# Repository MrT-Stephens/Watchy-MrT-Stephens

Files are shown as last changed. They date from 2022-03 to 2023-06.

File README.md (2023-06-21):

<h1 align="center">
  <br>
  MrT Stephens's Watchy GitHub Repo
  <br>
</h1>

<h4 align="center">This is my version of the Watchy E-Paper smartwatch by <a href="https://watchy.sqfmi.com" target="_blank">sqfmi</a>!</h4>

<p align="center">
  <a href="#watchy-esp32-s3">Watchy Esp32-S3</a> •
  <a href="#watchy-esp32-s3-specifications">Watchy Esp32-S3 specifications</a> •
   <a href="#watchy-esp32-s3-3d-models">Watchy Esp32-S3 3D-Models</a>
</p>

## Watchy Esp32-S3
***Current Version = V1.2***
> **Note**
> The version 1.2 has not been tested yet, as version 1.1 was having issues with the I2C bus.

## Watchy Esp32-S3 specifications
* MCU, ESP32-S3R8, Dual Core, 8MB Psram.
* Flash, 128Mbit, 16MB, W25Q128JVPIQ.
* Sensors.
   - BME688, Environmental Gas sensor.
   - BMP390, Pressure sensor.
   - BMA400, Accelerometer.
   - BMM150, Magnometer.
   - SHT41A, Temprature sensor.
   - DS3231MZ, Real Time clock.
* E-Paper Display, GDEH0154D67.
* Type C Port, USB4110-GF-A_REVB.
* PCB Antenna, swra117d.
* Tactical Buttons, K2-1114SA-A4SW-06.
* Vibration Motor.

## Watchy Esp32-S3 3D-Models
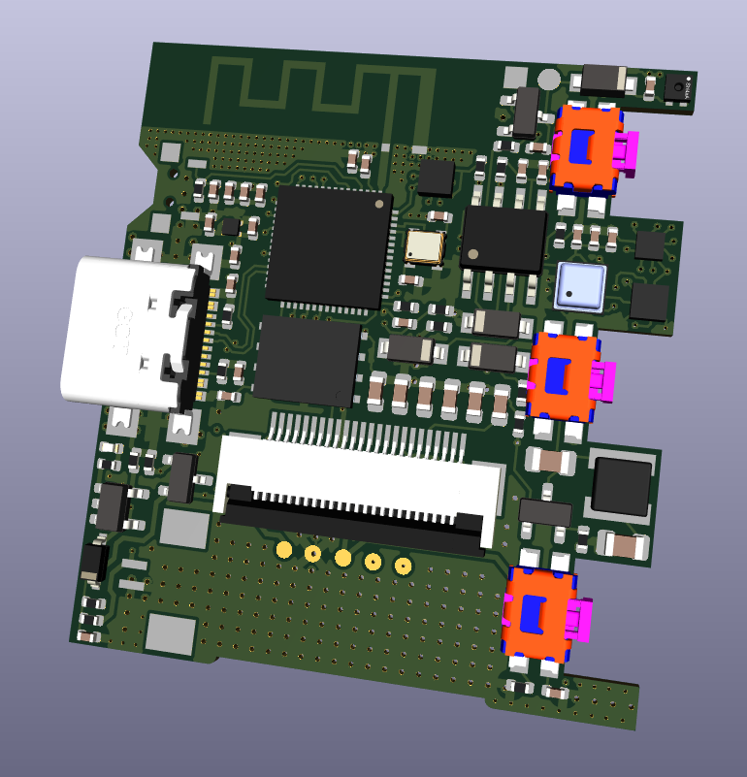
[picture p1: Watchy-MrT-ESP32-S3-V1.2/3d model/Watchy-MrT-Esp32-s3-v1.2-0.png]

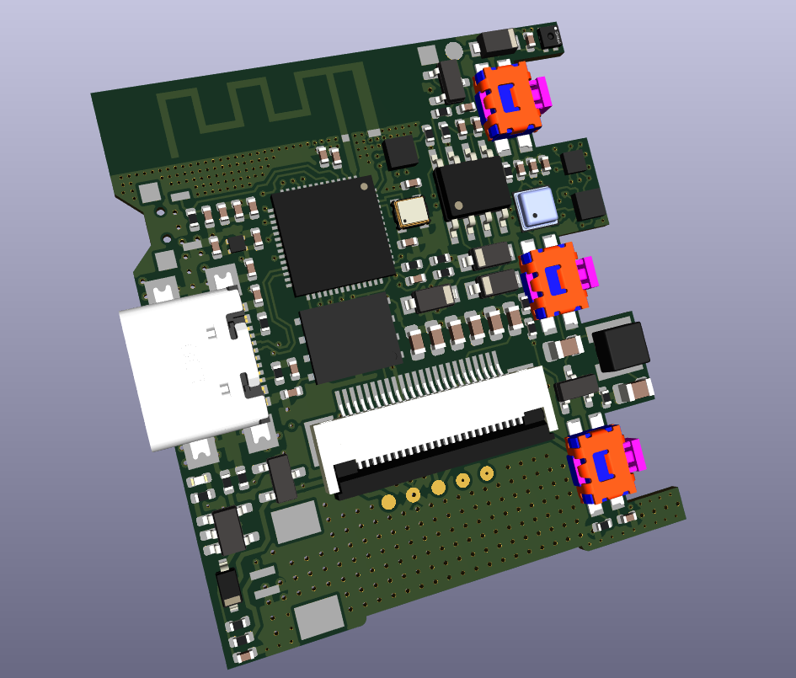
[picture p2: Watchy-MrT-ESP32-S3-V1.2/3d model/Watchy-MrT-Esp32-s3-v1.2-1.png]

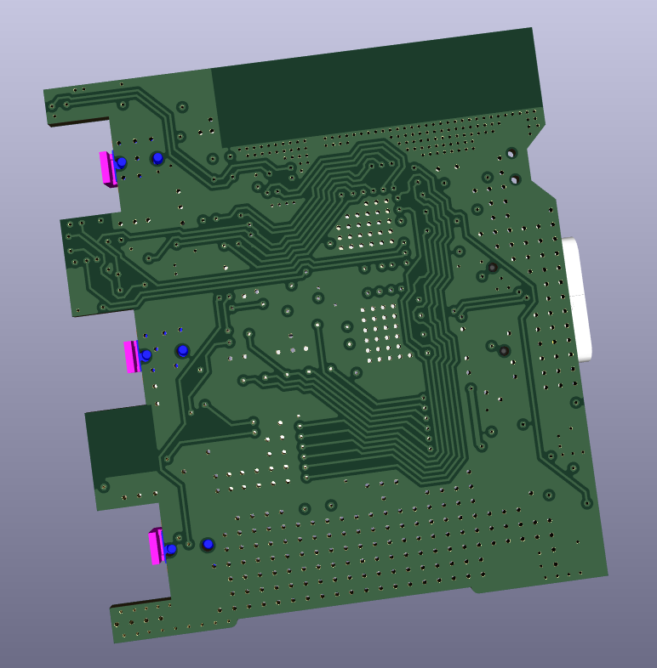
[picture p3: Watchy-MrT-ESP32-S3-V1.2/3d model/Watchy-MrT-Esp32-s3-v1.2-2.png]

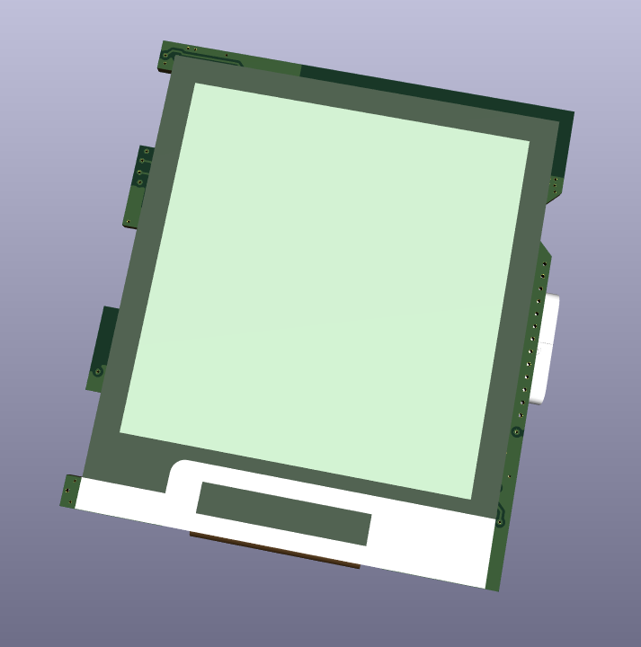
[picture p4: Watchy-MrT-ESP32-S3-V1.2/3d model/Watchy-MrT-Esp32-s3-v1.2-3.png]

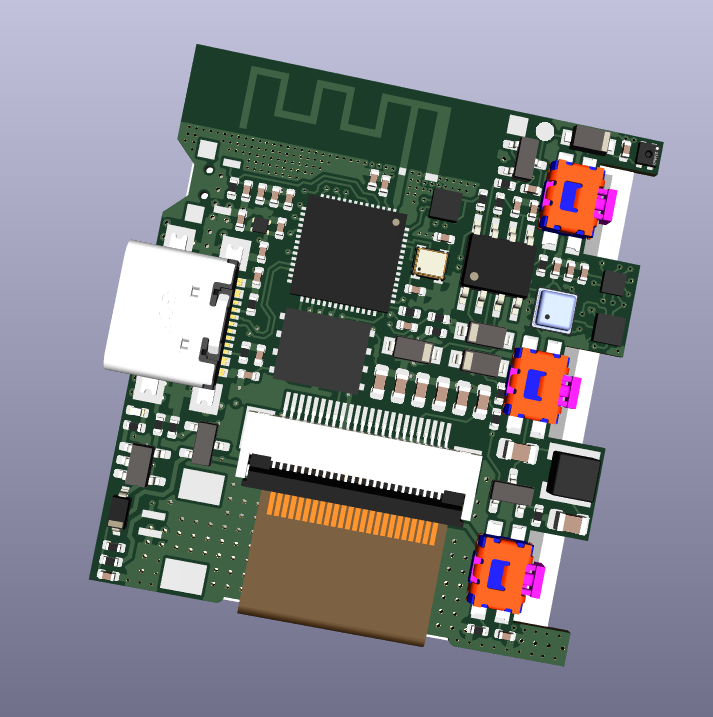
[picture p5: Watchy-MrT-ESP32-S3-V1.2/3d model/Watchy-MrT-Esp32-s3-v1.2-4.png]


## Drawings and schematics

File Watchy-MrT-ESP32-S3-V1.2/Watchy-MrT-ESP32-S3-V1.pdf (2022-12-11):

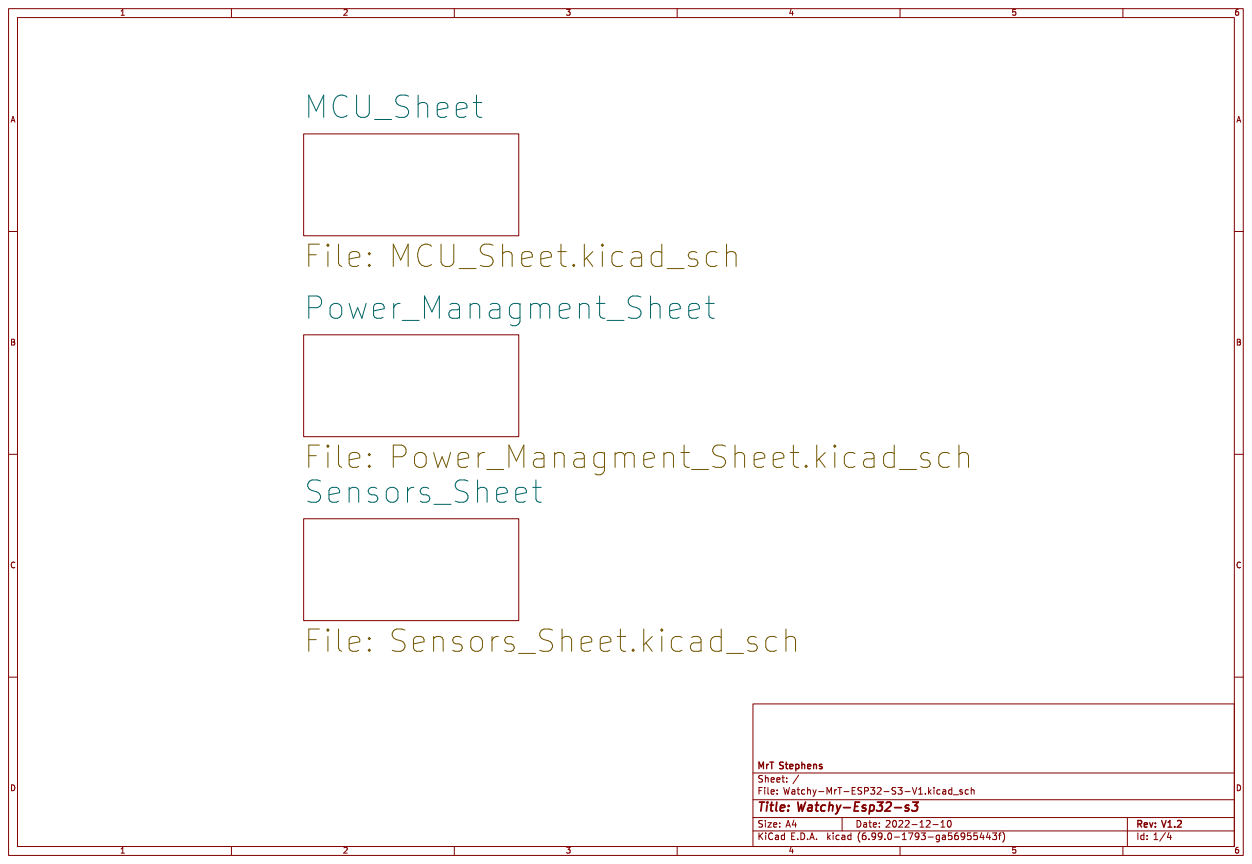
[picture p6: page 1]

File: Watchy-MrT-ESP32-S3-V1.kicad_sch Sheet: / MrT Stephens

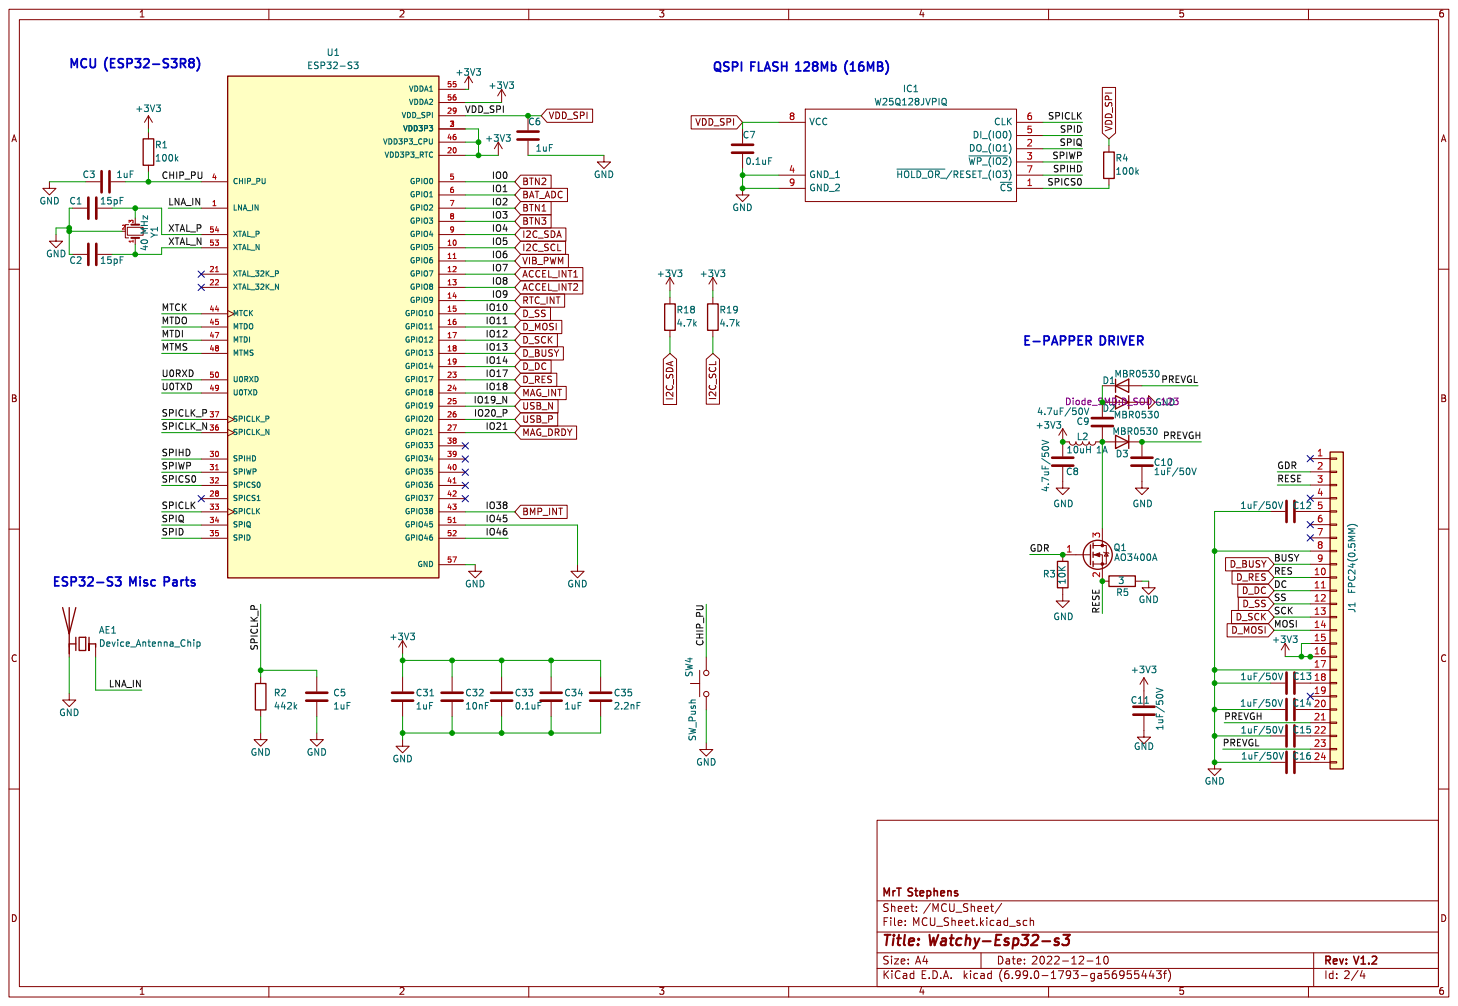
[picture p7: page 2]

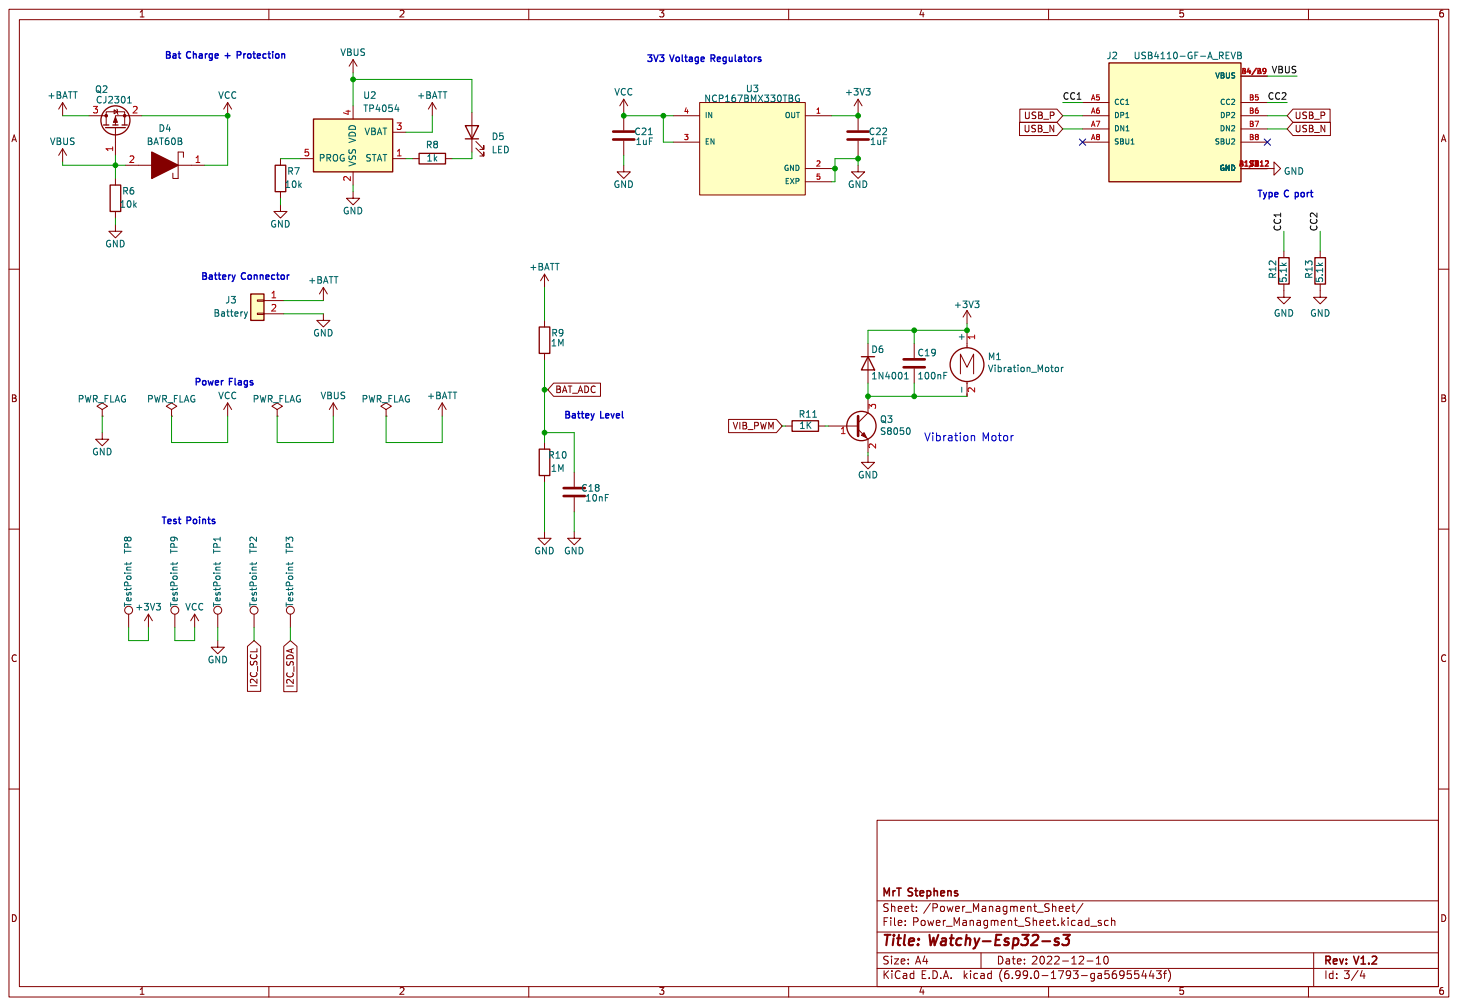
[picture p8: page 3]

Type C port Vibration Motor Bat Charge + Protection

Test Points Power Flags
PWR_FLAG

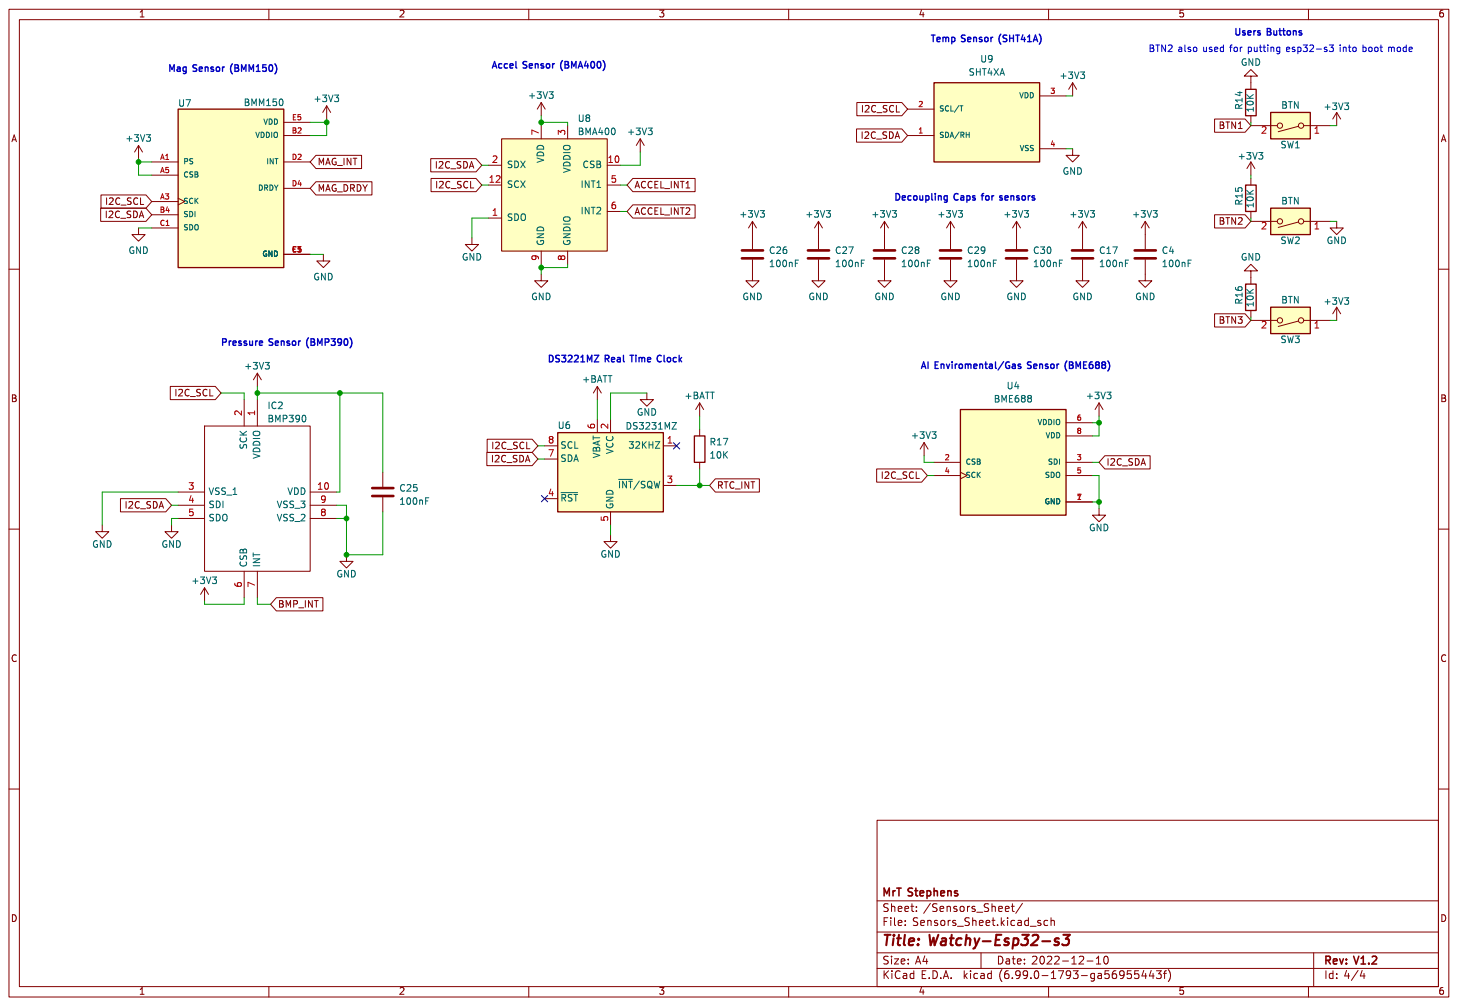
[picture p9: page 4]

Users Buttons BTN2 also used for putting esp32-s3 into boot mode

Decoupling Caps for sensors DS3221MZ Real Time Clock Pressure Sensor (BMP390)

6 SDA 7 SCL 8 U6 DS3231MZ GND GND

AI Enviromental/Gas Sensor (BME688)

2 ~{INT}/SQW 3 ~{RST} 4 GND

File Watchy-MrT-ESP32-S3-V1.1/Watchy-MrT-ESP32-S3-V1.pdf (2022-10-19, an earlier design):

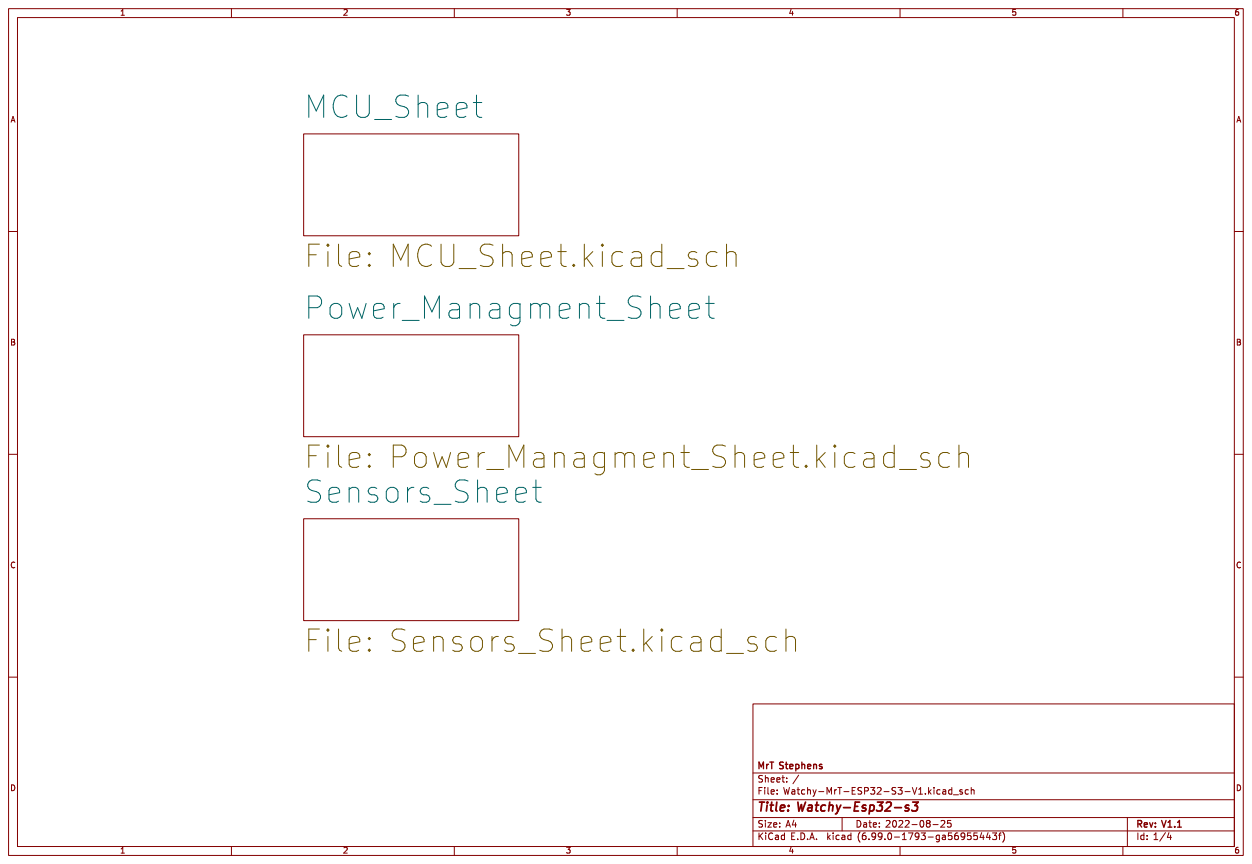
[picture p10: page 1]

File: Watchy-MrT-ESP32-S3-V1.kicad_sch Sheet: / MrT Stephens

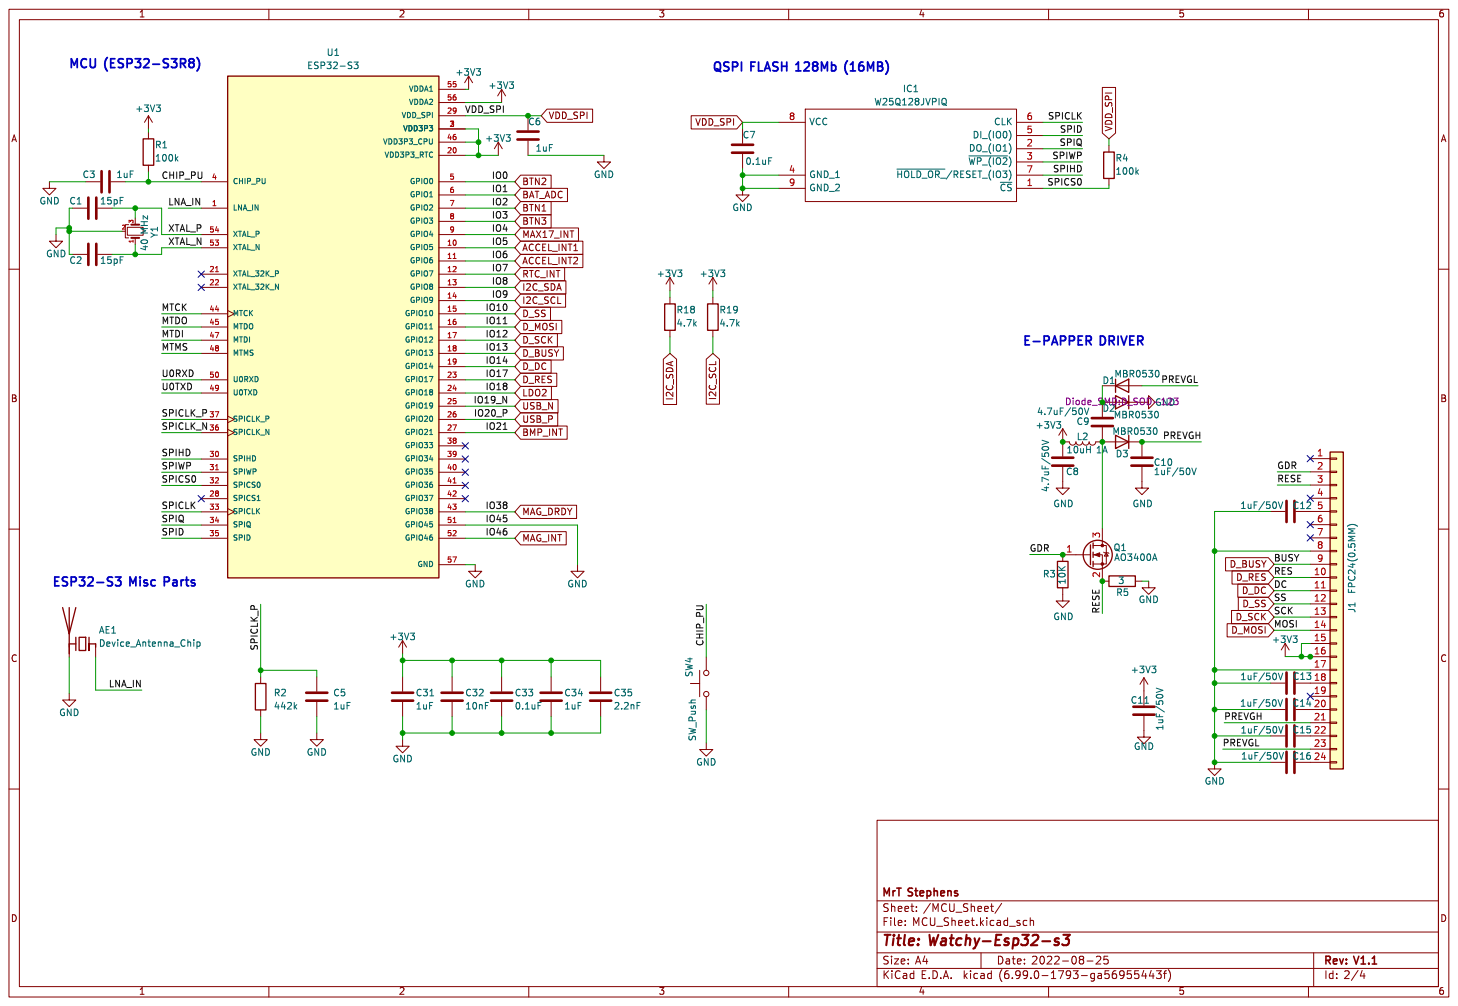
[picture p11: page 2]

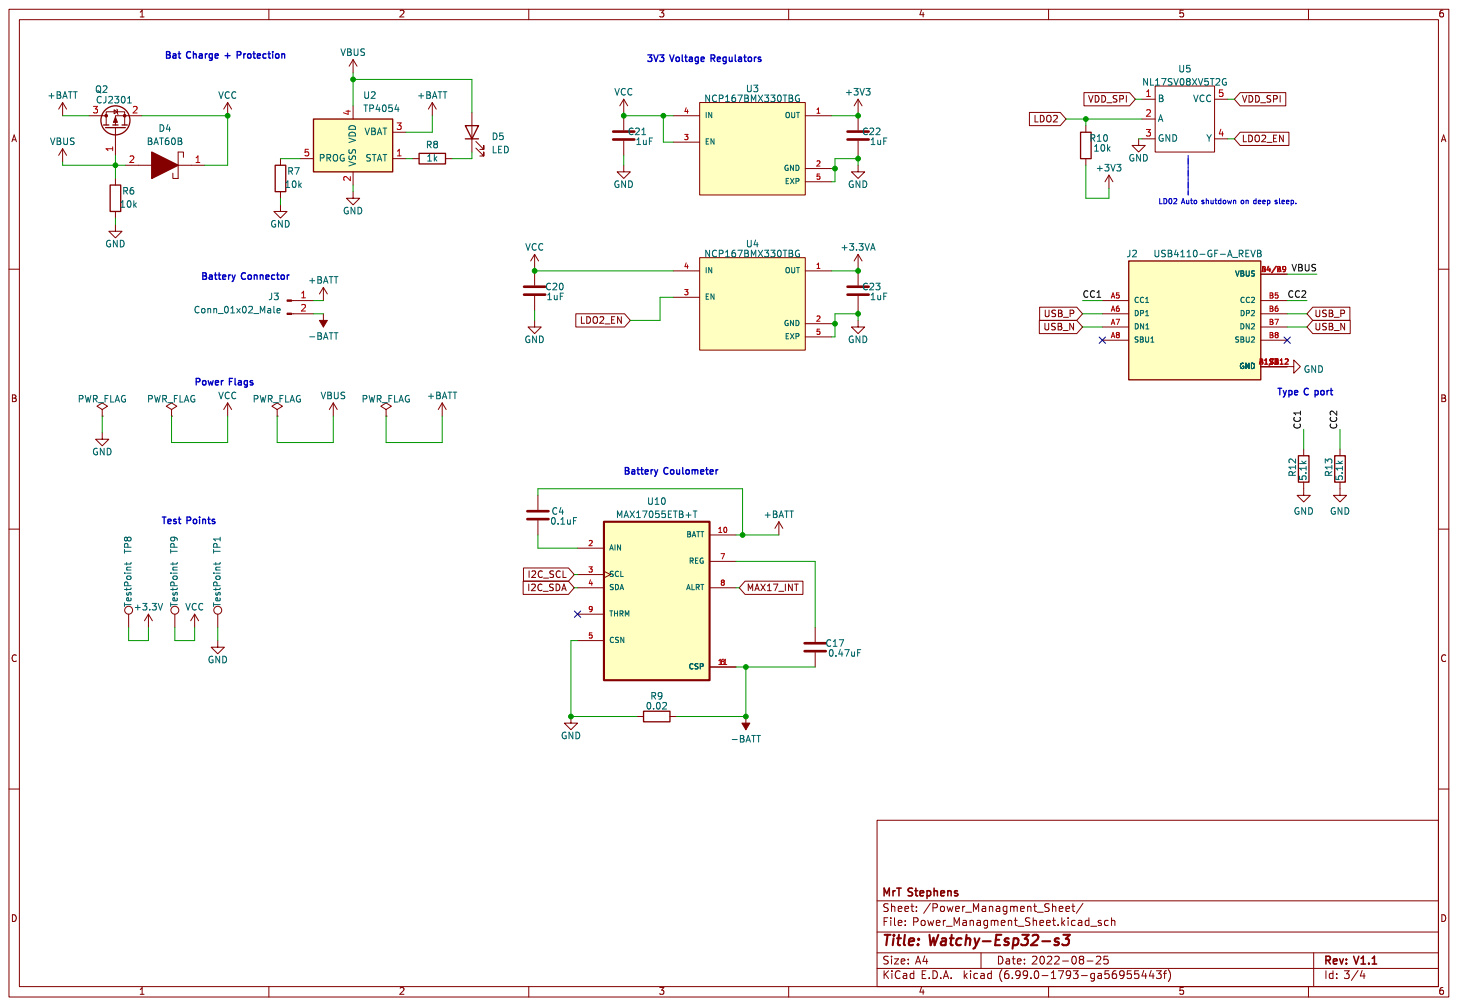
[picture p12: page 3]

LD02 Auto shutdown on deep sleep. Power Flags Test Points

VCC TP1 TestPoint TP8 TestPoint +3.3V GND

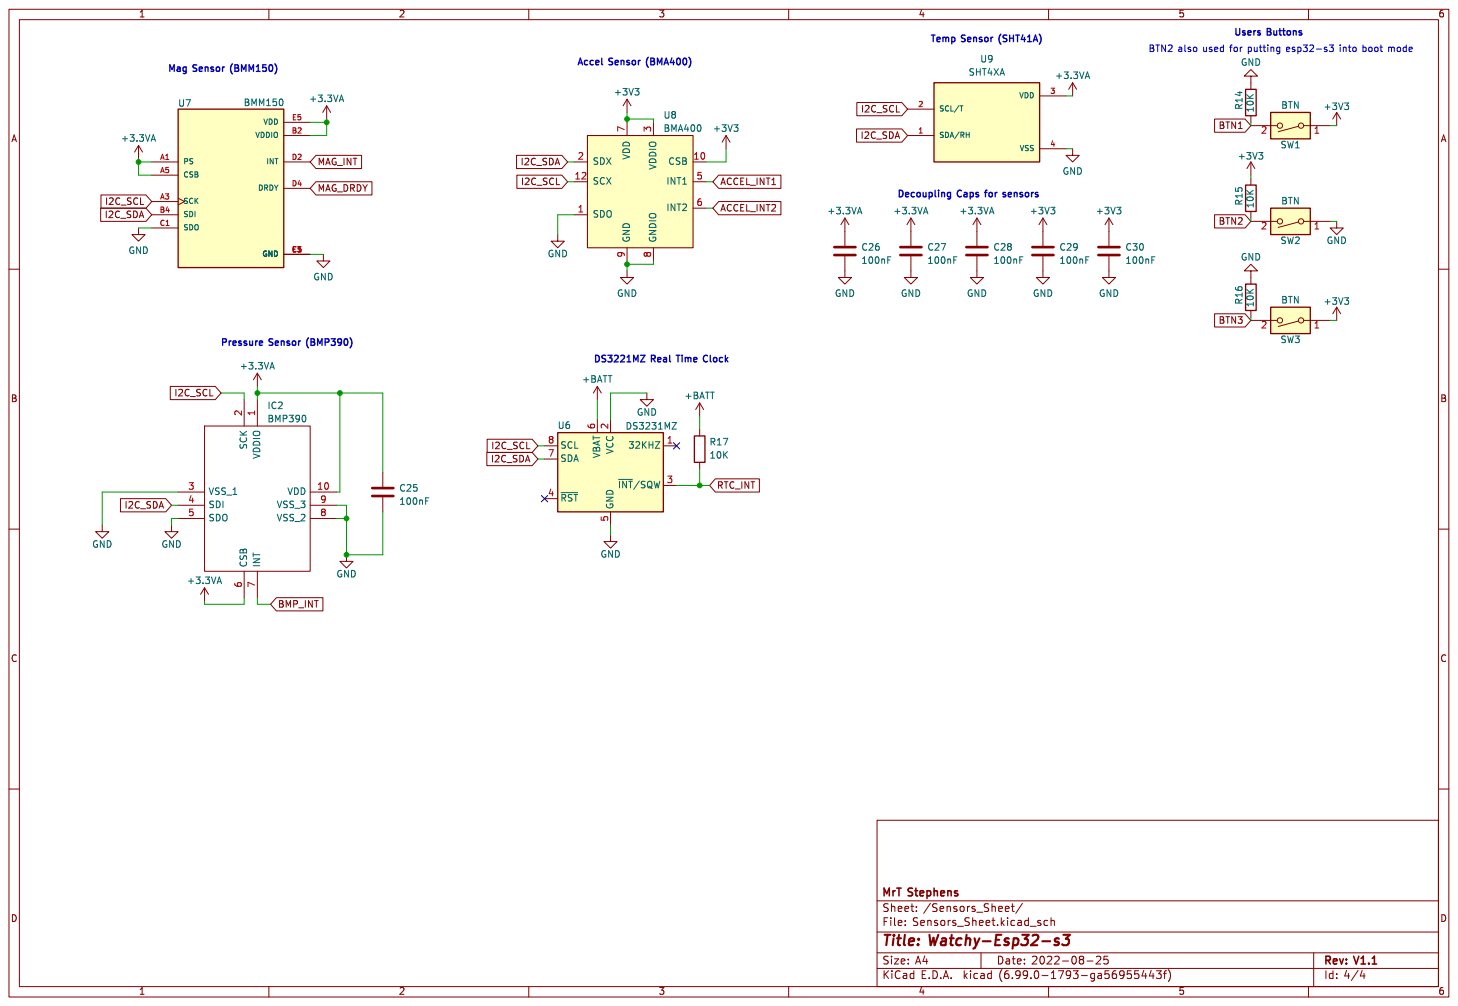
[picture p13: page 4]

2 ~{INT}/SQW 3 ~{RST} 4 GND

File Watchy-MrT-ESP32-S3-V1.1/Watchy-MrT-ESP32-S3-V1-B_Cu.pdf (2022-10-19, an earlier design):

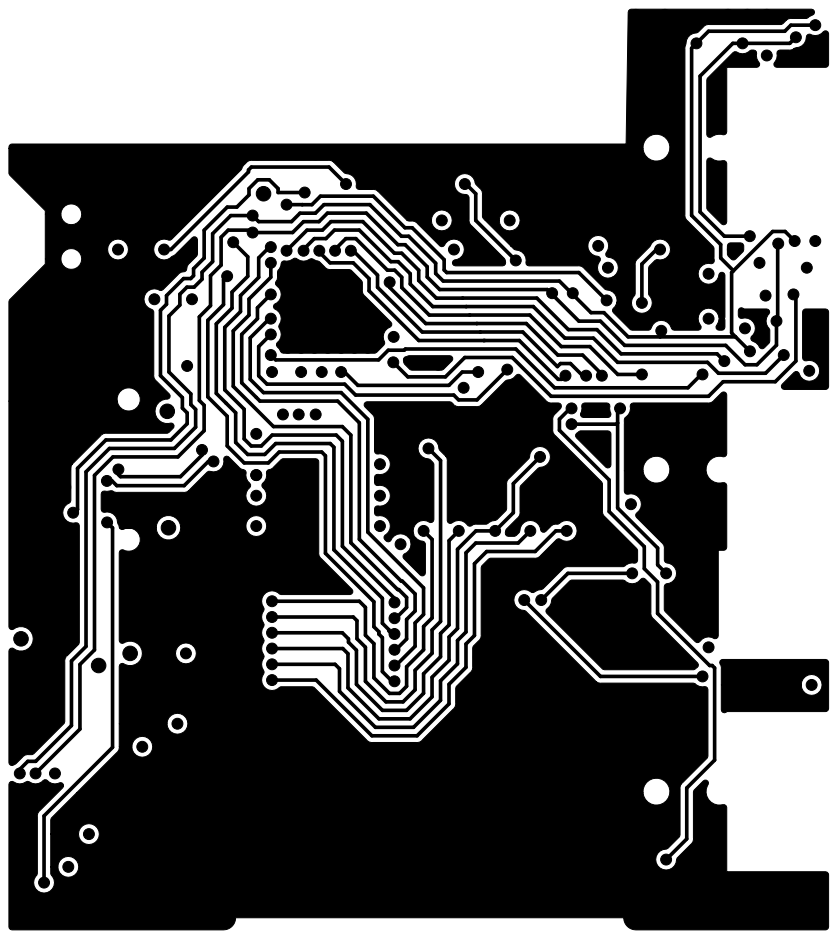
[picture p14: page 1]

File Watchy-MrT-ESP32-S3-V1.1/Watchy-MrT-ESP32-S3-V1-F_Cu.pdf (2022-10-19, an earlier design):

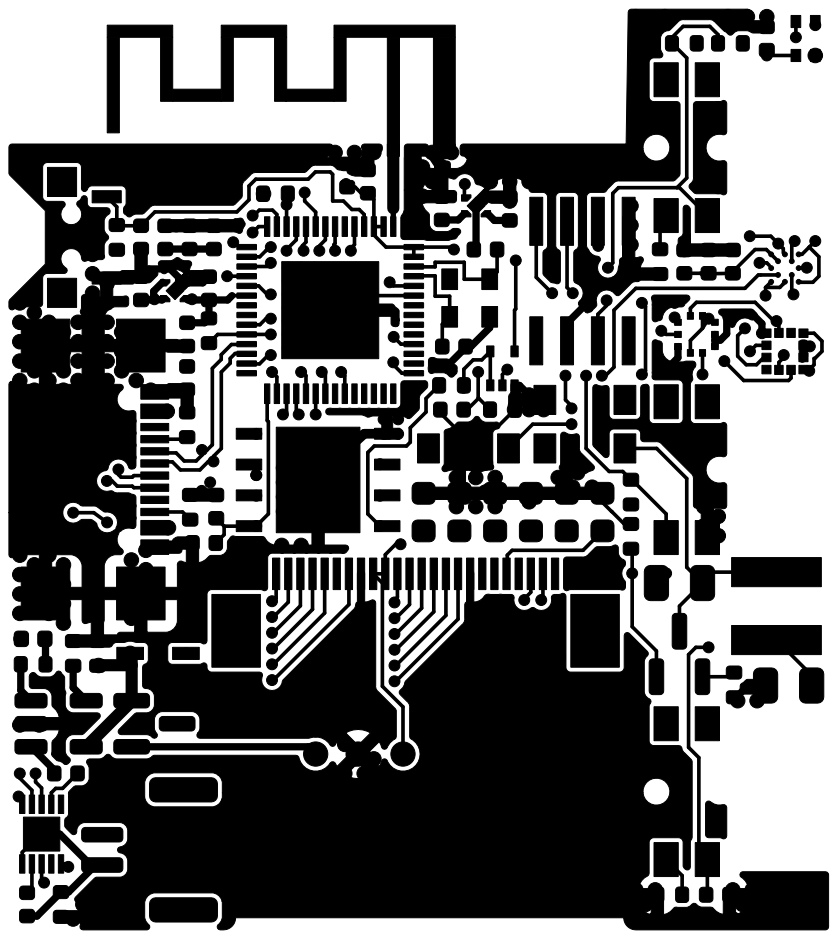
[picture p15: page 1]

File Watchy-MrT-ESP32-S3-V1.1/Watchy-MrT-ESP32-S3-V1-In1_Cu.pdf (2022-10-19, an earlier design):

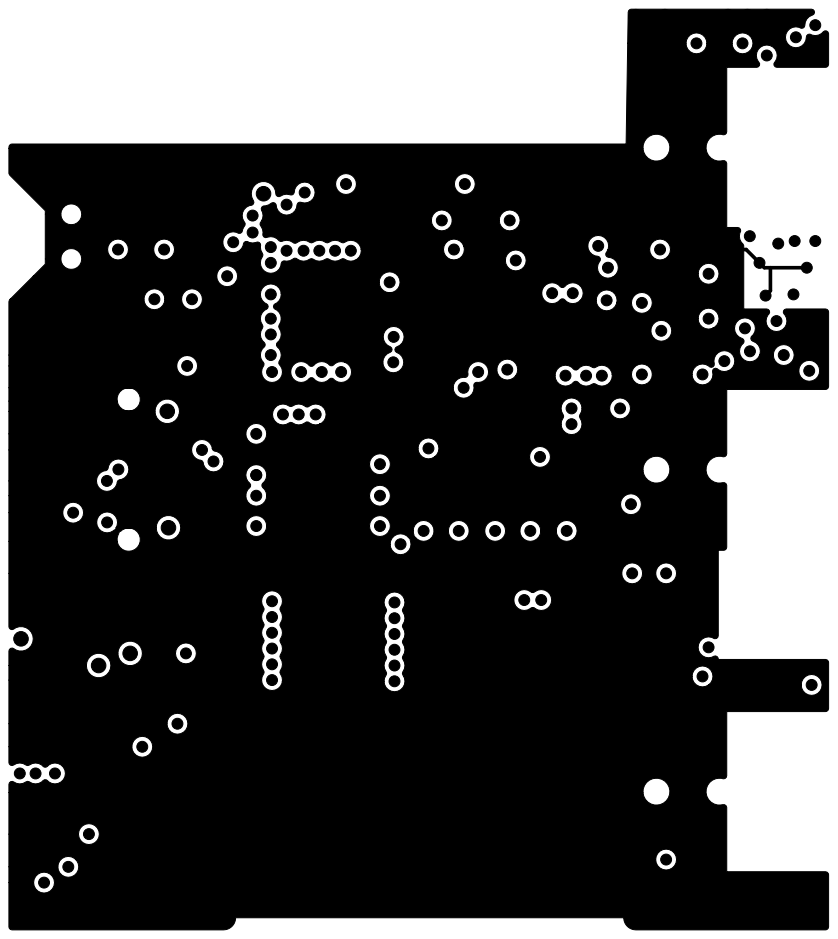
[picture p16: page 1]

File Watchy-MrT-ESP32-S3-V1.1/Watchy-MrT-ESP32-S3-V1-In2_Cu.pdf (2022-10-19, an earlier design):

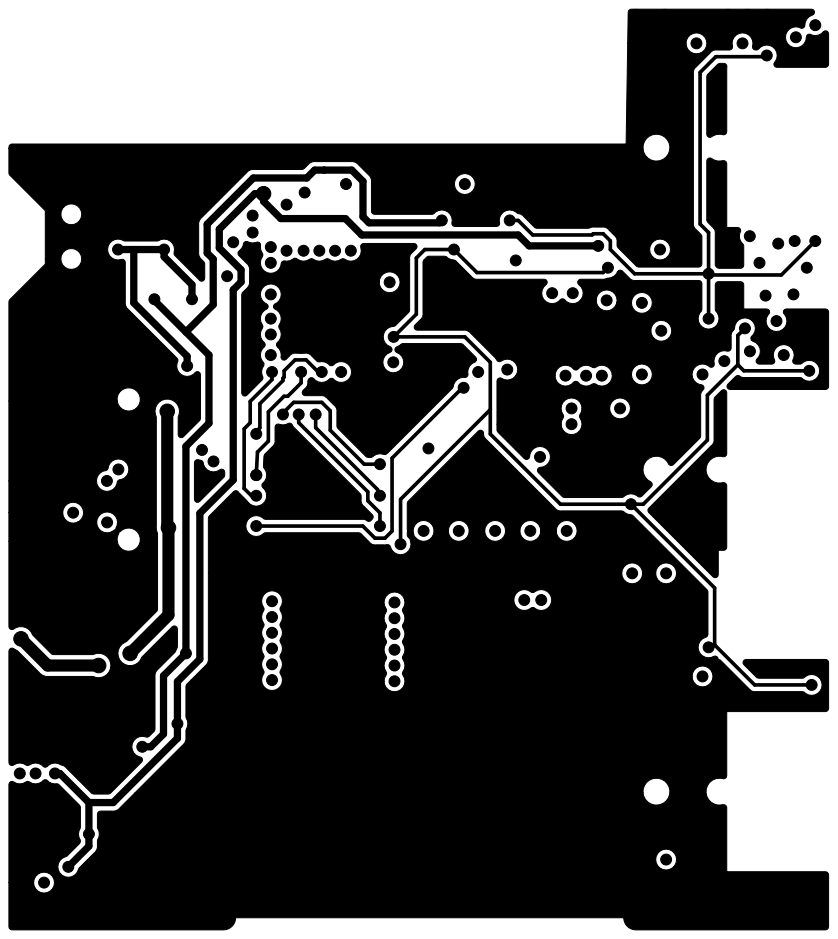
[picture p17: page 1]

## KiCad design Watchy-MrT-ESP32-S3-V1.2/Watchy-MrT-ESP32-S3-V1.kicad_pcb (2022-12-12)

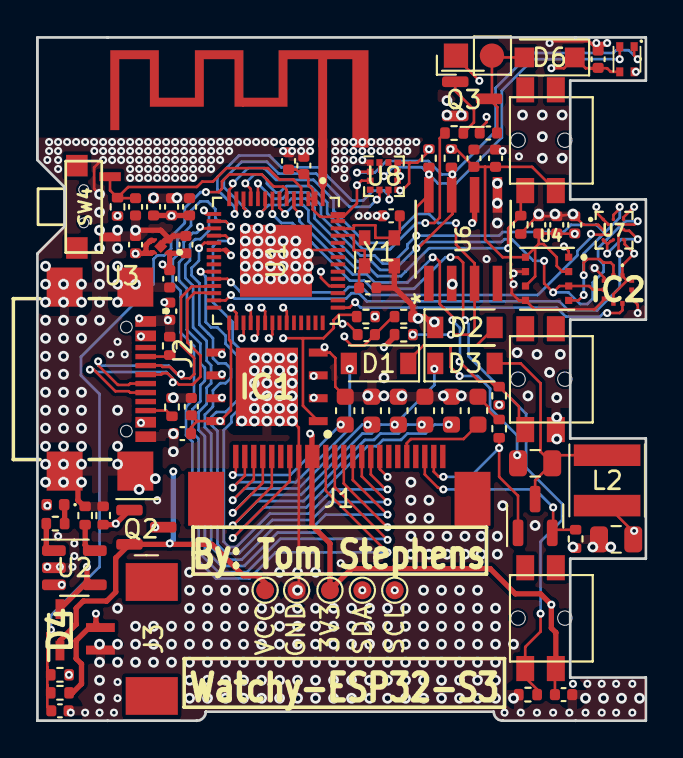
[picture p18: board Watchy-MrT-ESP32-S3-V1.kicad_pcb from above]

Board: 4 copper layers, 33.8 x 38.0 mm, 86 parts (0 on the bottom side), 56 nets.

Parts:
3V3: TestPoint; TestPoint_Pad_D1.0mm
AE1: Device_Antenna_Chip; SWRA117D
C1, C2: 15pF; C_0402_1005Metric
C3, C5, C6, C21, C22, C31, C34: 1uF; C_0402_1005Metric
C4, C17, C19, C25, C26, C27, C28, C29, C30: 100nF; C_0402_1005Metric
C7, C33: 0.1uF; C_0402_1005Metric
C8, C9: 4.7uF/50V; C_0805_2012Metric
C10, C12, C13, C14, C15, C16: 1uF/50V; C_0603_1608Metric
C11: 1uF/50V; C_0402_1005Metric
C18, C32: 10nF; C_0402_1005Metric
C35: 2.2nF; C_0402_1005Metric
D1, D2, D3: MBR0530; D_SOD-123
D4: BAT60B; SOD2512X115N
D5: LED; LED_0402_1005Metric
D6: 1N4001; D_SOD-123F
GND: TestPoint; TestPoint_Pad_D1.0mm
IC1: W25Q128JVPIQ; SON127P600X500X80-9N-D
IC2: BMP390
J1: FPC24(0.5MM); 24_Pins_0.5mm_Pitch_ZIF_Connector_UP
J2: USB4110-GF-A_REVB; GCT_USB4110-GF-A_REVB
J3: Battery; 1.25T-2PWT (Molex 532610271)
L2: 10uH 1A; L_Taiyo-Yuden_NR-40xx
M1: Vibration_Motor; Motor_Header
Q1: AO3400A; SOT-23
Q2: CJ2301; SOT-23
Q3: S8050; SOT-23
R1, R4: 100k; R_0402_1005Metric
R2: 442k; R_0402_1005Metric
R3, R14, R15, R16, R17: 10K; R_0402_1005Metric
R5: 3; R_0402_1005Metric
R6, R7: 10k; R_0402_1005Metric
R8: 1k; R_0402_1005Metric
R9, R10: 1M; R_0402_1005Metric
R11: 1K; R_0402_1005Metric
R12, R13: 5.1k; R_0402_1005Metric
R18, R19: 4.7k; R_0402_1005Metric
SCL: TestPoint; TestPoint_Pad_D1.0mm
SDA: TestPoint; TestPoint_Pad_D1.0mm
SW1, SW2, SW3: BTN; K2-1114SA-A4SW-06
SW4: SW_Push; button_side_smd
U1: ESP32-S3; QFN40P700X700X90-57N
U2: TP4054; SOT-23-5
U3: NCP167BMX330TBG; REG_NCP167BMX330TBG
U4: BME688; IC_BME688
U6: DS3231MZ; 21-0041B_8
U7: BMM150; XDCR_BMM150
U8: BMA400; LGA-12_2x2mm_P0.5mm
U9: SHT4XA
VCC: TestPoint; TestPoint_Pad_D1.0mm
Y1: 40 MHz; Oscillator_SMD_Abracon_ASDMB-4Pin_2.5x2.0mm

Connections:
+3V3: 3V3.1, C4.1, C8.1, C11.1, C17.1, C19.1, C22.2, C25.1, C26.1, C27.1, C28.1, C29.1, C30.1, C31.1, C32.1, C33.1, C34.1, C35.1, D6.1 (K), IC2.1 (VDDIO), IC2.6 (CSB), IC2.10 (VDD), J1.15, J1.16, L2.2, M1.1 (+), R1.1, R15.1, R18.1, R19.1, SW1.1, SW3.1, U1.2 (VDD3P3), U1.3 (VDD3P3), U1.20 (VDD3P3_RTC), U1.46 (VDD3P3_CPU), U1.55 (VDDA1), U1.56 (VDDA2), U3.1 (OUT), U4.2 (CSB), U4.6 (VDDIO), U4.8 (VDD), U7.A1 (PS), U7.A5 (CSB), U7.B2 (VDDIO), U7.E5 (VDD), U8.3 (VDDIO), U8.7 (VDD), U8.10 (CSB), U9.3 (VDD)
+BATT: J3.1, Q2.3 (D), R9.1, R17.1, U2.3 (VBAT), U6.6 (VBAT)
/MCU_Sheet/CHIP_PU: C3.2, R1.2, SW4.2, U1.4 (CHIP_PU)
/MCU_Sheet/GDR: J1.2, Q1.1 (G), R3.1
/MCU_Sheet/LNA_IN: AE1.1 (FEED), U1.1 (LNA_IN)
/MCU_Sheet/PREVGH: C10.1, D3.1 (K), J1.21
/MCU_Sheet/PREVGL: D1.2 (A), J1.23
/MCU_Sheet/RESE: J1.3, Q1.2 (S), R5.2
/MCU_Sheet/SPICLK: IC1.6 (CLK), U1.33 (SPICLK)
/MCU_Sheet/SPICLK_P: C5.1, R2.1, U1.37 (SPICLK_P)
/MCU_Sheet/SPICS0: IC1.1 (~CS), R4.2, U1.32 (SPICS0)
/MCU_Sheet/SPID: IC1.5 (DI_(IO0)), U1.35 (SPID)
/MCU_Sheet/SPIHD: IC1.7 (~HOLD_OR_/RESET_(IO3)), U1.30 (SPIHD)
/MCU_Sheet/SPIQ: IC1.2 (DO_(IO1)), U1.34 (SPIQ)
/MCU_Sheet/SPIWP: IC1.3 (~WP_(IO2)), U1.31 (SPIWP)
/MCU_Sheet/XTAL_N: C2.2, U1.53 (XTAL_N), Y1.1
/MCU_Sheet/XTAL_P: C1.2, U1.54 (XTAL_P), Y1.3
/Power_Managment_Sheet/CC1: J2.A5 (CC1), R12.1
/Power_Managment_Sheet/CC2: J2.B5 (CC2), R13.1
ACCEL_INT1: U1.12 (GPIO7), U8.5 (INT1)
ACCEL_INT2: U1.13 (GPIO8), U8.6 (INT2)
BAT_ADC: C18.1, R9.2, R10.1, U1.6 (GPIO1)
BMP_INT: IC2.7 (INT), U1.43 (GPIO38)
BTN1: R14.2, SW1.2, U1.7 (GPIO2)
BTN2: R15.2, SW2.2, U1.5 (GPIO0)
BTN3: R16.2, SW3.2, U1.8 (GPIO3)
D_BUSY: J1.9, U1.18 (GPIO13)
D_DC: J1.11, U1.19 (GPIO14)
D_MOSI: J1.14, U1.16 (GPIO11)
D_RES: J1.10, U1.23 (GPIO17)
D_SCK: J1.13, U1.17 (GPIO12)
D_SS: J1.12, U1.15 (GPIO10)
GND: AE1.2 (PCB_Trace), C1.1, C2.1, C3.1, C4.2, C5.2, C6.2, C7.2, C8.2, C10.2, C11.2, C12.2, C13.2, C14.2, C15.2, C16.2, C17.2, C18.2, C21.1, C22.1, C25.2, C26.2, C27.2, C28.2, C29.2, C30.2, C31.2, C32.2, C33.2, C34.2, C35.2, D2.1 (K), GND.1, IC1.4 (GND_1), IC1.9 (GND_2), IC2.3 (VSS_1), IC2.5 (SDO), IC2.8 (VSS_2), IC2.9 (VSS_3), J1.8, J1.17, J2.A1/B12 (GND), J2.B1/A12 (GND), J2.S1 (GND), J2.S2 (GND), J2.S3 (GND), J2.S4 (GND), J3.2, Q3.2 (E), R2.2, R3.2, R5.1, R6.2, R7.2, R10.2, R12.2, R13.2, R14.1, R16.1, SW2.1, SW4.1, U1.51 (GPIO45), U1.57 (GND), U2.2 (VSS), U3.2 (GND), U3.5 (EXP), U4.1 (GND), U4.5 (SDO), U4.7 (GND), U6.2 (VCC), U6.5 (GND), U7.C1 (SDO), U7.C5 (GND), U7.E1 (GND), U7.E3 (GND), U8.1 (SDO), U8.8 (GNDIO), U8.9 (GND), U9.4 (VSS), Y1.2
I2C_SCL: IC2.2 (SCK), R19.2, SCL.1, U1.10 (GPIO5), U4.4 (SCK), U6.8 (SCL), U7.A3 (SCK), U8.12 (SCX), U9.2 (SCL/T)
I2C_SDA: IC2.4 (SDI), R18.2, SDA.1, U1.9 (GPIO4), U4.3 (SDI), U6.7 (SDA), U7.B4 (SDI), U8.2 (SDX), U9.1 (SDA/RH)
MAG_DRDY: U1.27 (GPIO21), U7.D4 (DRDY)
MAG_INT: U1.24 (GPIO18), U7.D2 (INT)
unnamed: C9.1, D1.1 (K), D2.2 (A)
unnamed: C9.2, D3.2 (A), L2.1, Q1.3 (D)
unnamed: D5.1 (K), R8.1
unnamed: C19.2, D6.2 (A), M1.2 (-), Q3.3 (C)
unnamed: C12.1, J1.5
unnamed: C13.1, J1.18
unnamed: C14.1, J1.20
unnamed: C15.1, J1.22
unnamed: C16.1, J1.24
unnamed: Q3.1 (B), R11.1
unnamed: R7.1, U2.5 (PROG)
unnamed: R8.2, U2.1 (STAT)
RTC_INT: R17.2, U1.14 (GPIO9), U6.3 (~INT/SQW)
USB_N: J2.A7 (DN1), J2.B7 (DN2), U1.25 (GPIO19)
USB_P: J2.A6 (DP1), J2.B6 (DP2), U1.26 (GPIO20)
VBUS: D4.2, D5.2 (A), J2.A4/B9 (VBUS), J2.B4/A9 (VBUS), Q2.1 (G), R6.1, U2.4 (VDD)
VCC: C21.2, D4.1, Q2.2 (S), U3.3 (EN), U3.4 (IN), VCC.1
VDD_SPI: C6.1, C7.1, IC1.8 (VCC), R4.1, U1.29 (VDD_SPI)
VIB_PWM: R11.2, U1.11 (GPIO6)

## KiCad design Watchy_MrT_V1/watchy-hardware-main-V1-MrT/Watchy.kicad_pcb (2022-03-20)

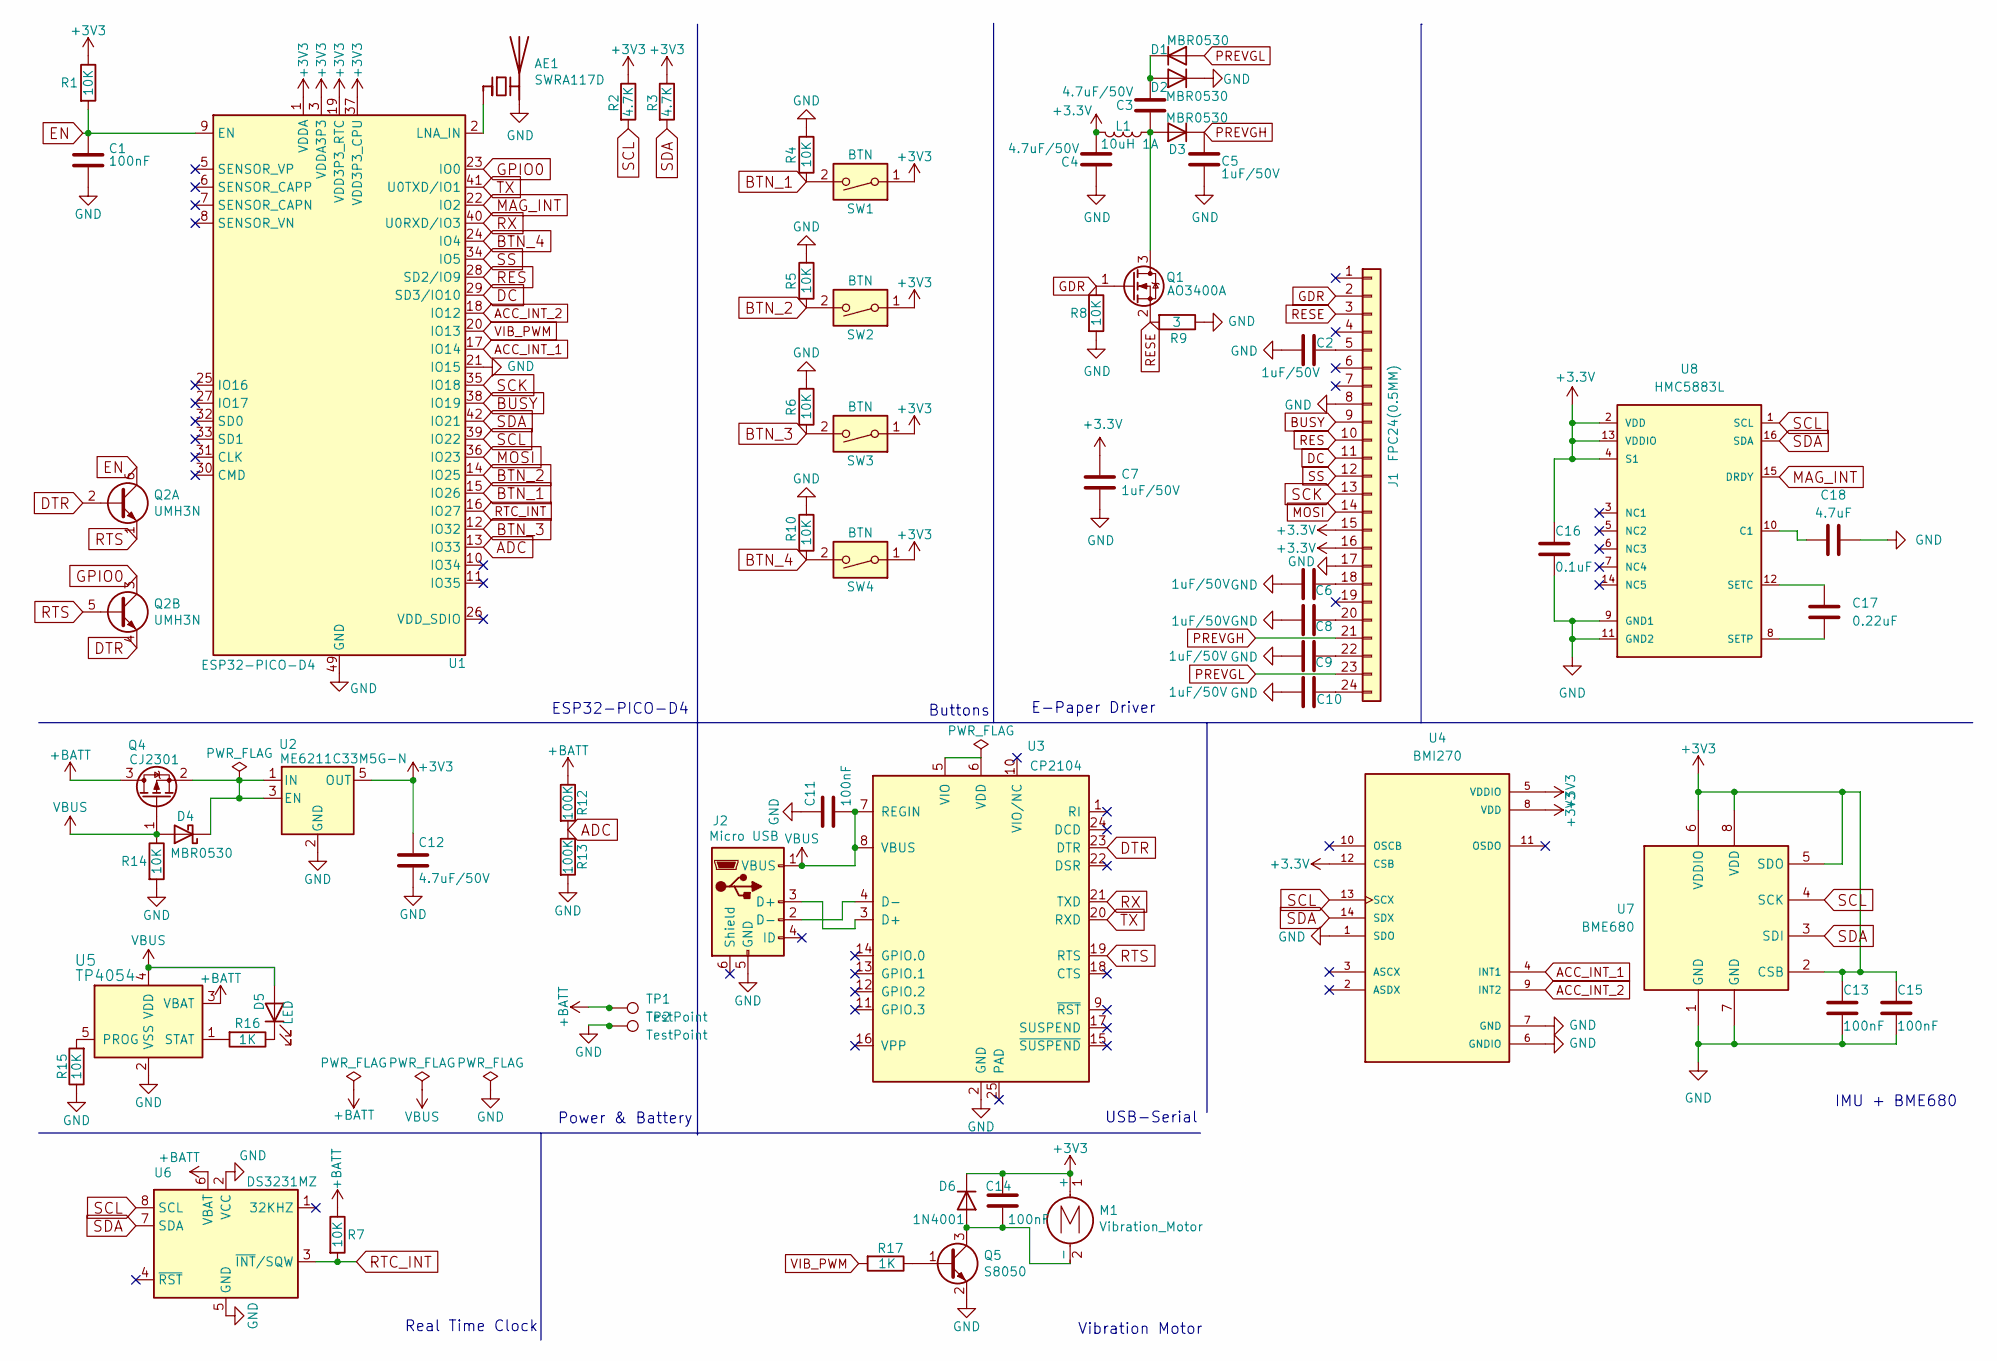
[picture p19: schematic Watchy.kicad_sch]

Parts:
AE1: SWRA117D
C1, C11, C13, C14, C15: 100nF; C_0603_1608Metric
C2, C5, C6, C7, C8, C9, C10: 1uF/50V; C_0603_1608Metric
C3, C4, C12: 4.7uF/50V; C_0805
C16: 0.1uF; C_0603_1608Metric
C17: 0.22uF; C_0603_1608Metric
C18: 4.7uF; C_0603_1608Metric
D1, D2, D3, D4: MBR0530; D_SOD-123
D5: LED; LED_0603
D6: 1N4001; D_SOD-123F
J1: FPC24(0.5MM); 24_Pins_0.5mm_Pitch_ZIF_Connector_UP
J2: Micro USB; USB_Micro-B
L1: 10uH 1A; Inductor_Taiyo-Yuden_NR-40xx
M1: Vibration_Motor; Motor_Header
Q1: AO3400A; SOT-23
Q2: UMH3N; SOT-363_SC-70-6
Q4: CJ2301; SOT-23
Q5: S8050; SOT-23
R1, R4, R5, R6, R7, R8, R10, R14, R15: 10K; R_0402
R2, R3: 4.7K; R_0402
R9: 3; R_0402
R12, R13: 100K; R_0402
R16, R17: 1K; R_0402
SW1, SW2, SW3, SW4: BTN; K2-1114SA-A4SW-06
TP1, TP2: TestPoint; TestPoint_Pad_2.0x2.0mm
U1: ESP32-PICO-D4; QFN-48-1EP_7x7mm_Pitch0.5mm
U2: ME6211C33M5G-N; SOT-23-5
U3: CP2104; QFN-24-1EP_4x4mm_P0.5mm_EP2.6x2.6mm
U4: BMI270; XDCR_BMI270
U5: TP4054; SOT-23-5
U6: DS3231MZ; SOIC-8_3.9x4.9mm_Pitch1.27mm
U7: BME680; Bosch_LGA-8_3x3mm_P0.8mm_ClockwisePinNumbering
U8: HMC5883L

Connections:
+BATT: Q4.3 (D), R7.1, R12.1, TP1.1, U5.3 (VBAT), U6.6 (VBAT); also elsewhere on the board
ACC_INT_1: U1.17 (IO14), U4.4 (INT1)
ACC_INT_2: U1.18 (IO12), U4.9 (INT2)
ADC: R12.2, R13.1, U1.13 (IO33)
BTN_1: R4.2, SW1.2, U1.15 (IO26)
BTN_2: R5.2, SW2.2, U1.14 (IO25)
BTN_3: R6.2, SW3.2, U1.12 (IO32)
BTN_4: R10.2, SW4.2, U1.24 (IO4)
BUSY: J1.9, U1.38 (IO19)
DC: J1.11, U1.29 (SD3/IO10)
DTR: Q2.2 (B1), Q2.4 (E2), U3.23 (DTR)
EN: C1.1, Q2.6 (C1), R1.2, U1.9 (EN)
GDR: J1.2, Q1.1 (G), R8.1
GND: AE1.2 (PCB_Trace), C1.2, C2.2, C4.2, C5.2, C6.2, C7.2, C8.2, C9.2, C10.2, C11.1, C12.2, C13.2, C15.2, C16.2, C18.2, D2.1 (K), J1.8, J1.17, J2.5 (GND), Q5.2 (E), R4.1, R5.1, R6.1, R8.2, R9.1, R10.1, R13.2, R14.2, R15.1, TP2.1, U1.21 (IO15), U1.49 (GND), U2.2 (GND), U3.2 (GND), U4.1 (SDO), U4.6 (GNDIO), U4.7 (GND), U5.2 (VSS), U6.2 (VCC), U6.5 (GND), U7.1 (GND), U7.7 (GND), U8.9 (GND1), U8.11 (GND2); also elsewhere on the board
GPIO0: Q2.3 (C2), U1.23 (IO0)
MAG_INT: U1.22 (IO2), U8.15 (DRDY)
MOSI: J1.14, U1.36 (IO23)
unnamed: AE1.1 (FEED), U1.2 (LNA_IN)
unnamed: C3.1, D1.1 (K), D2.2 (A)
unnamed: C3.2, D3.2 (A), L1.1, Q1.3 (D)
unnamed: D4.1 (K), Q4.2 (S), U2.1 (IN), U2.3 (EN)
unnamed: D5.1 (K), R16.1
unnamed: C14.2, D6.2 (A), M1.2 (-), Q5.3 (C)
unnamed: C2.1, J1.5
unnamed: C6.1, J1.18
unnamed: C8.1, J1.20
unnamed: C9.1, J1.22
unnamed: C10.1, J1.24
unnamed: J2.3 (D+), U3.3 (D+)
unnamed: J2.2 (D-), U3.4 (D-)
unnamed: Q5.1 (B), R17.1
unnamed: U3.5 (VIO), U3.6 (VDD)
unnamed: R15.2, U5.5 (PROG)
unnamed: R16.2, U5.1 (STAT)
unnamed: C18.1, U8.10 (C1)
unnamed: C17.1, U8.12 (SETC)
unnamed: C17.2, U8.8 (SETP)
PREVGH: C5.1, D3.1 (K), J1.21
PREVGL: D1.2 (A), J1.23
RES: J1.10, U1.28 (SD2/IO9)
RESE: J1.3, Q1.2 (S), R9.2
RTC_INT: R7.2, U1.16 (IO27), U6.3 (~INT/SQW)
RTS: Q2.1 (E1), Q2.5 (B2), U3.19 (RTS)
RX: U1.40 (U0RXD/IO3), U3.21 (TXD)
SCK: J1.13, U1.35 (IO18)
SCL: R2.2, U1.39 (IO22), U4.13 (SCX), U6.8 (SCL), U7.4 (SCK), U8.1 (SCL)
SDA: R3.2, U1.42 (IO21), U4.14 (SDX), U6.7 (SDA), U7.3 (SDI), U8.16 (SDA)
SS: J1.12, U1.34 (IO5)
TX: U1.41 (U0TXD/IO1), U3.20 (RXD)
VBUS: C11.2, D4.2 (A), D5.2 (A), J2.1 (VBUS), Q4.1 (G), R14.1, U3.7 (REGIN), U3.8 (VBUS), U5.4 (VDD)
VIB_PWM: R17.2, U1.20 (IO13)

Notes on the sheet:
Buttons
Vibration Motor
ESP32-PICO-D4
IMU + BME680
USB-Serial
Power & Battery
Real Time Clock
E-Paper Driver

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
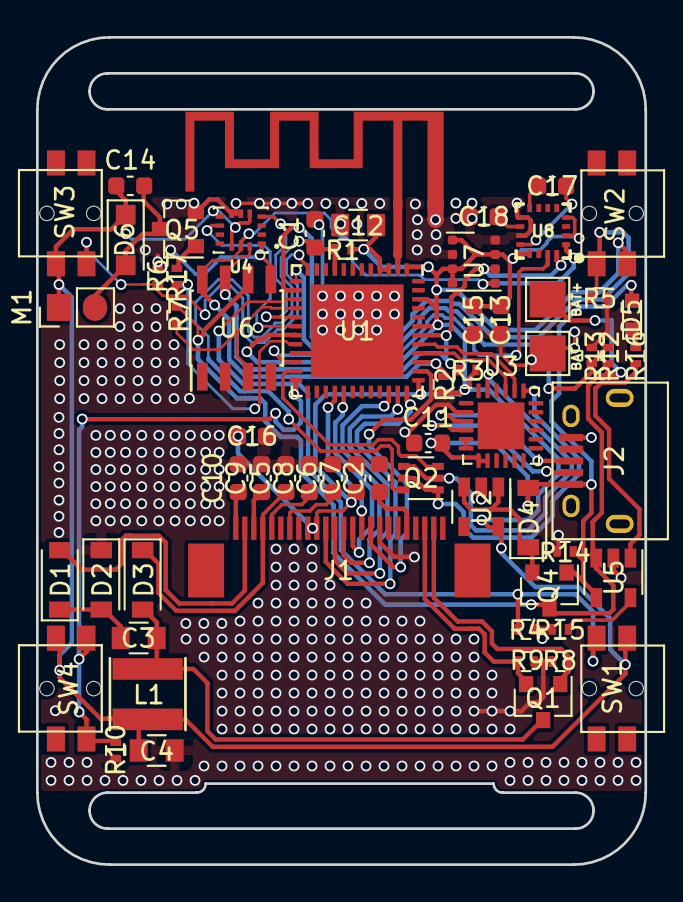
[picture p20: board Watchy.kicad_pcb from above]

Board: 2 copper layers, 33.8 x 46.0 mm, 63 parts (0 on the bottom side), 52 nets.

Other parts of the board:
BAT+: TestPoint; TestPoint_Pad_2.0x2.0mm
BAT-: TestPoint; TestPoint_Pad_2.0x2.0mm

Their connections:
+BATT: BAT+.1; also elsewhere on the board
GND: BAT-.1; also elsewhere on the board

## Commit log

2022-03-20 This is version 1 of my custom Watchy.
    [Battery402030.step, Button.step, Display.step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]
2022-12-12 Added 3d-models
    [Watchy-MrT-ESP32-S3-V1.kicad_pcb]
